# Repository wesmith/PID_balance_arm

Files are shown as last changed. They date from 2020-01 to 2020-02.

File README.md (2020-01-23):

PID_balance_arm

Implement and experiment with a balancing arm that demonstrates PID control, based upon
the project by Electronoobs:

https://www.youtube.com/watch?v=JFTJ2SS4xyA

I want to thank Electronoobs for pushing me over the edge to finally get a 3D printer
after watching this video.

For the 3D modeling, .blend and .stl files were created with Blender,
.gcode files were created with Cura, and printed on an Ender 3 Pro.

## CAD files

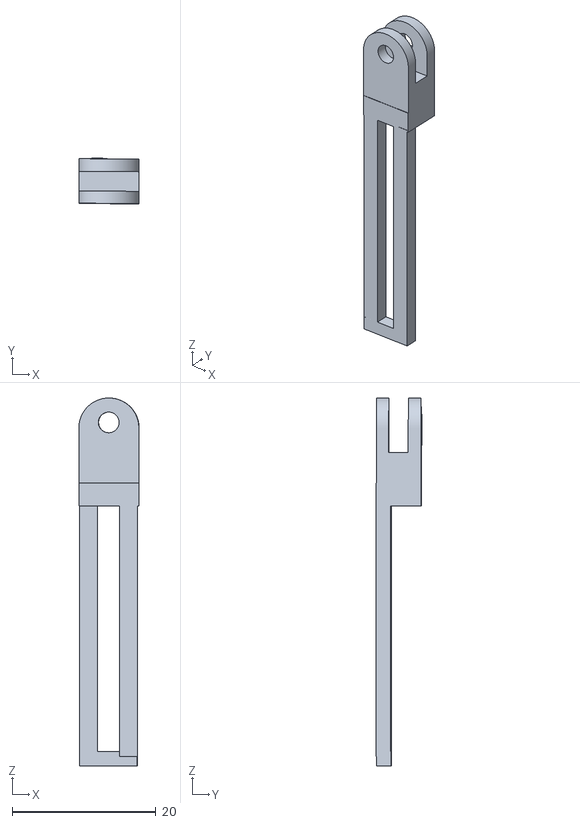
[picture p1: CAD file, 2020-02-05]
electronoobs_balance_3D_files/stl/ws-modified-top-bottom-hinge-single.stl
8.41 x 6.46 x 51.2

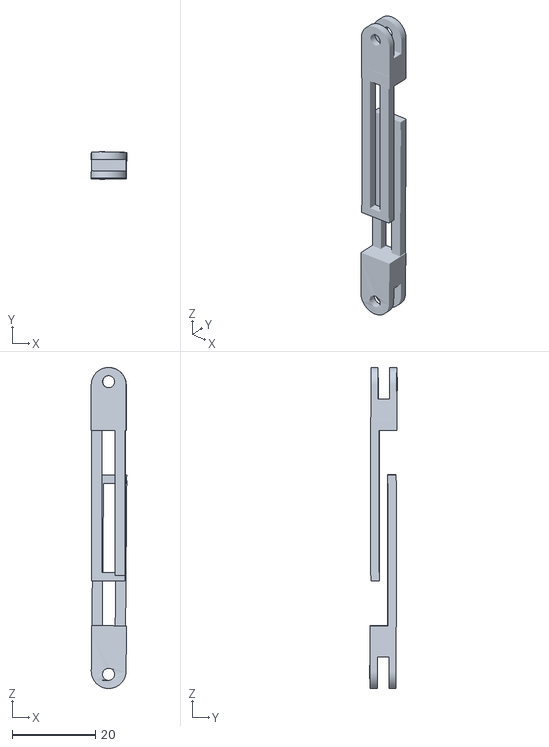
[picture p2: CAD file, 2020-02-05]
electronoobs_balance_3D_files/stl/ws-modified-top-bottom-hinge.stl
8.53 x 6.70 x 77.0

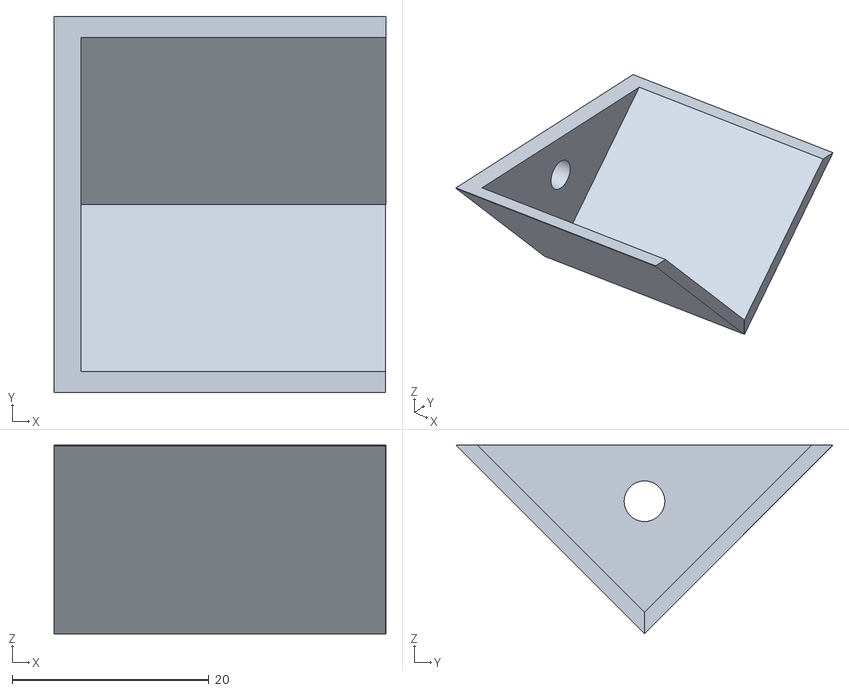
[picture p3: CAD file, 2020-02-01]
electronoobs_balance_3D_files/stl/ws-end_stop.stl
33.7 x 38.2 x 19.2

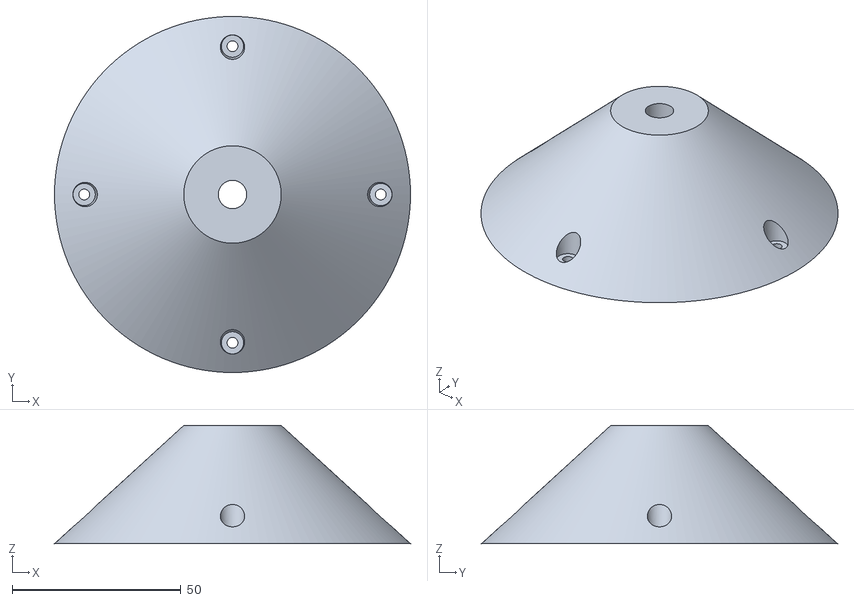
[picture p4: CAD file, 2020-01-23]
electronoobs_balance_3D_files/stl/Base.stl
105.6 x 105.6 x 35.1

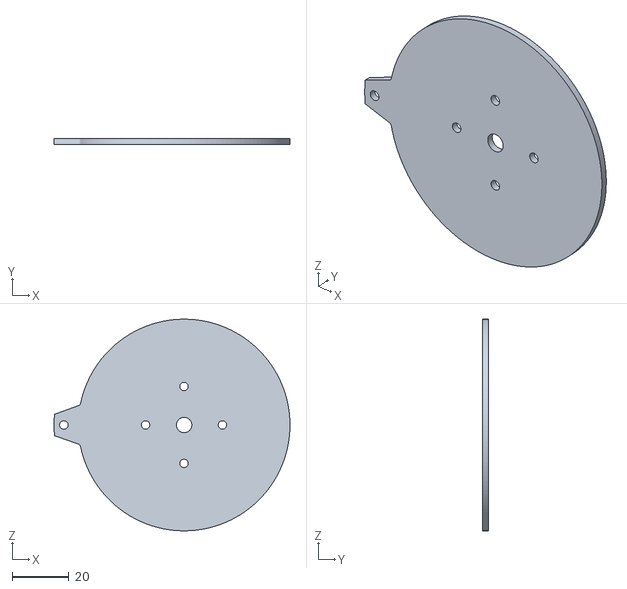
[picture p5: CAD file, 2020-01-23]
electronoobs_balance_3D_files/stl/Disc3.stl
82.9 x 2.00 x 74.4

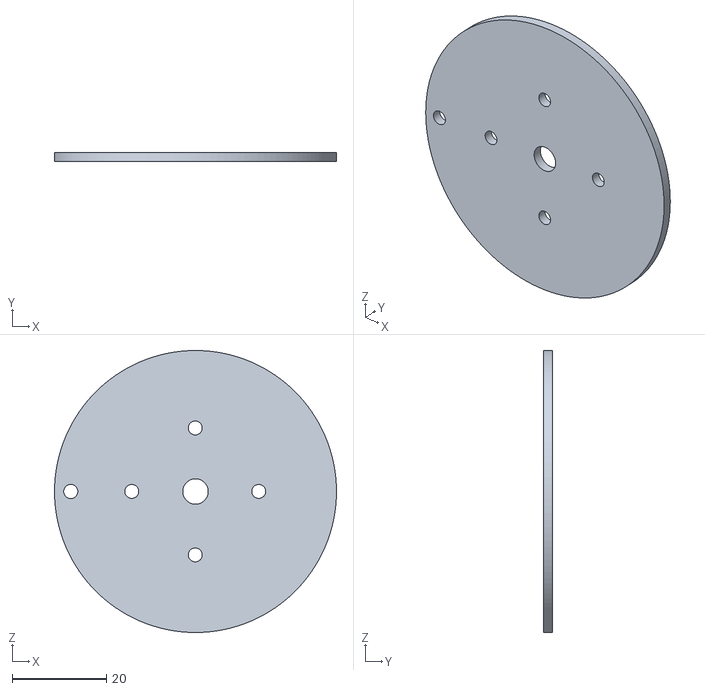
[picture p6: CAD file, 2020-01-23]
electronoobs_balance_3D_files/stl/Disc.stl
60.0 x 2.00 x 60.0

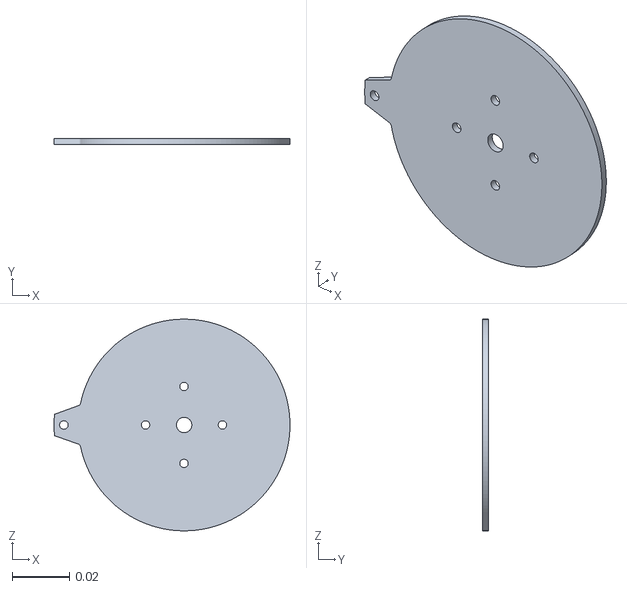
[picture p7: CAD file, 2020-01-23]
electronoobs_balance_3D_files/stl/WS-disc3-scaled-shifted.stl
0.0828 x 0.002 x 0.0743

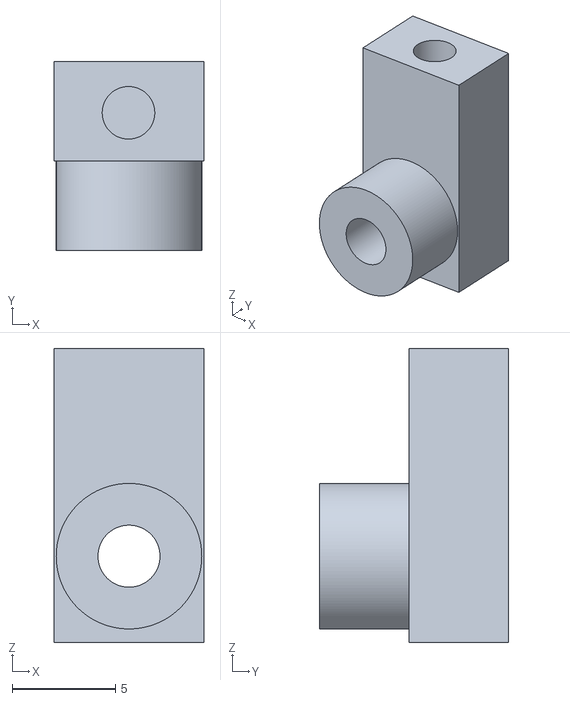
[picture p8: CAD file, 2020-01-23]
electronoobs_balance_3D_files/stl/Small_hinge_3.stl
7.23 x 9.14 x 14.2

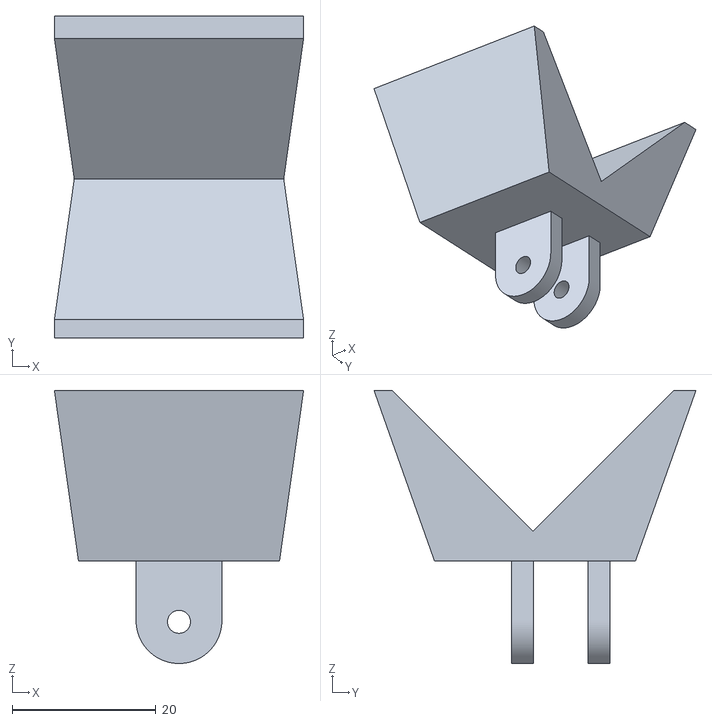
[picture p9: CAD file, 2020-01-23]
electronoobs_balance_3D_files/stl/Hinge_2.stl
34.7 x 44.8 x 38.0

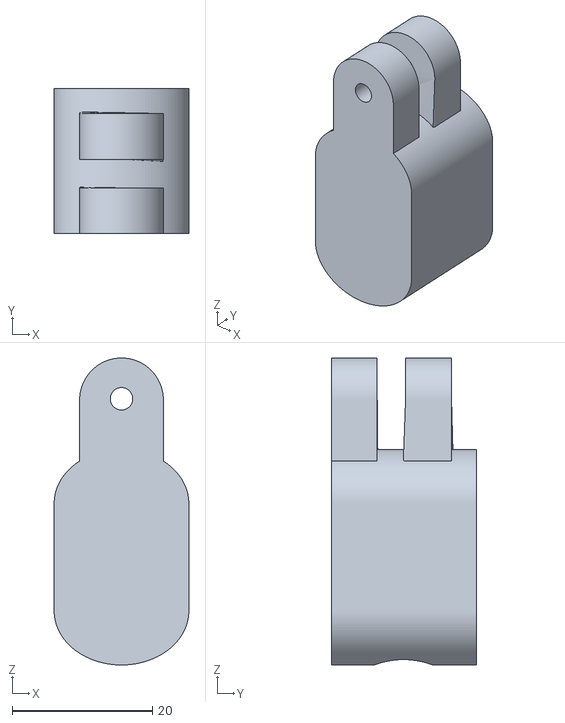
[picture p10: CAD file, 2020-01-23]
electronoobs_balance_3D_files/stl/Hinge_1.stl
19.2 x 20.8 x 43.9

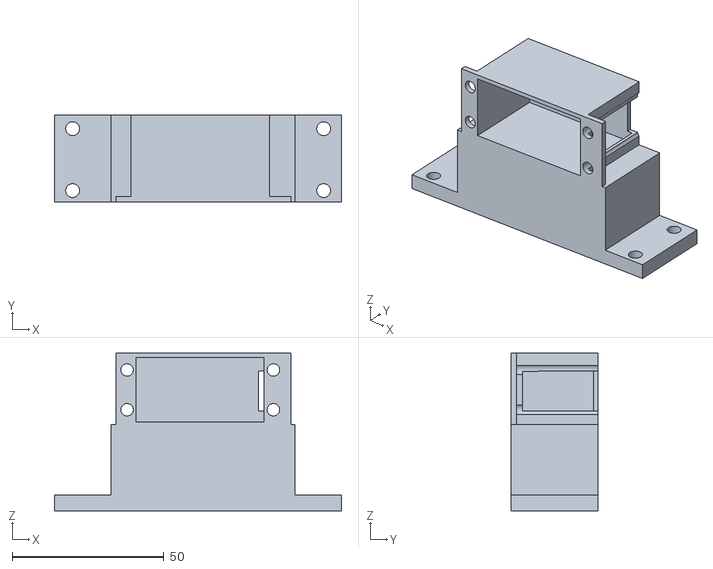
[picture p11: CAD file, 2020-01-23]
electronoobs_balance_3D_files/stl/Servo_support.stl
94.6 x 28.7 x 51.9

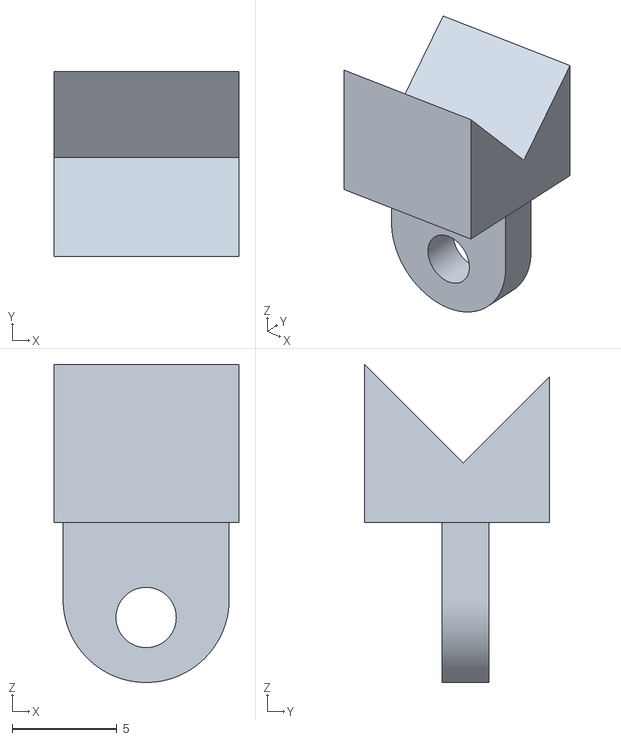
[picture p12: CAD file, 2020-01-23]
electronoobs_balance_3D_files/stl/Small_hinge_1.stl
8.83 x 8.83 x 15.2

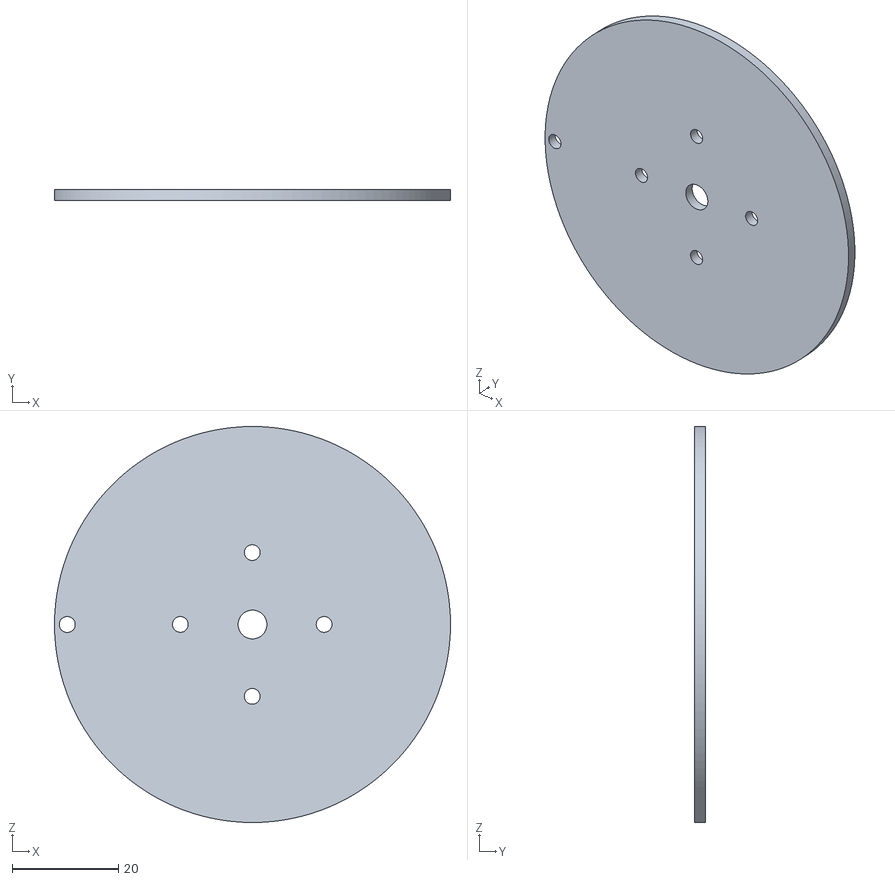
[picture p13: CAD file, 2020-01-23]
electronoobs_balance_3D_files/stl/Disc2.stl
74.4 x 2.00 x 74.4

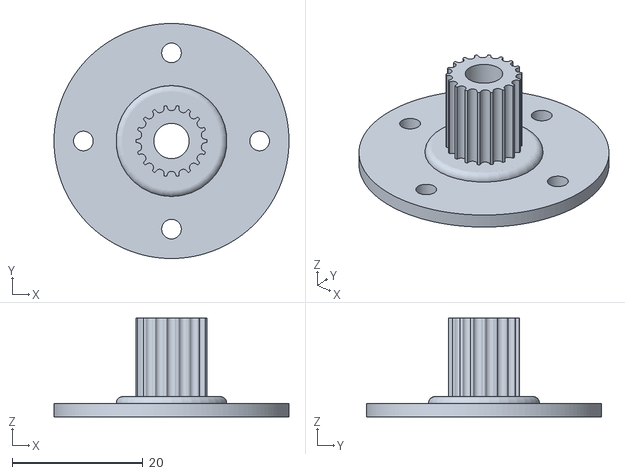
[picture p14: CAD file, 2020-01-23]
electronoobs_balance_3D_files/stl/6. Small_gear (2x).stl
36.0 x 36.0 x 15.1

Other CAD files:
electronoobs_balance_3D_files/stl/ws-bar.stl
electronoobs_balance_3D_files/stl/Small_hinge_2.stl
electronoobs_balance_3D_files/stl/ws-lever.stl
electronoobs_balance_3D_files/stl/End_stop.stl
electronoobs_balance_3D_files/blend/Balanza PID pingpong.blend
electronoobs_balance_3D_files/blend/ws-bar.blend
electronoobs_balance_3D_files/blend/ws-lever.blend
electronoobs_balance_3D_files/blend/ws-modified-top-bottom-hinge.blend

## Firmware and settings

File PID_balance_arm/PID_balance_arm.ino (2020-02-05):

/*PID_balance_arm.ino
 * 
 * WESmith 02/05/20
 * 
 * balance a ping-pong ball along a balance arm using PID feedback 
 * 
 * original code by http://electronoobs.com/eng_arduino_tut100_code1.php , 
 * modified for experimentation
 * 
 * hardware: Arduino UNO, GP2Y0A21YK0F_5V IR distance sensor (connected to pin A0), 
 *           and the Tower Pro SG-5010 servo (connected to pin 9)
 * 
 * NOTE: Before loading this program into the Arduino, remove the lever arm from the servo
 *       to prevent spurious out-of-bound motion of the servo during program startup 
 *       from damaging/stressing the setup. After the program has initialized, put the lever 
 *       arm on the servo in the horizontal position, which corresponds to the beginning 
 *       servo_ang of 90 deg. 
 */

#include "IR_sensor.h" 
#include <Servo.h>

int NMEAS             =  100; // 60  number of distance measurements to average for 1 point
const int MINANG      =  65; // in deg
const int MAXANG      = 115; 

const byte sensor_pin =  A0;
const byte servo_pin  =   9;


float servo_ang = 90; 
int   baseline  = 90; // baseline angle of slide

unsigned int analog; // not used in this sketch, but required for get_dist()
unsigned int distance;

DistSensor sensor(DistSensor::GP2Y0A21YK0F_5V, sensor_pin);
Servo servo;

////////////////////////Variables///////////////////////
float tt;
float prev_error = 0;
float error      = 0;
int   period     = 20;  // refresh rate of the loop in ms
///////////////////////////////////////////////////////

///////////////////PID constants///////////////////////
float alpha = 0.9; 
float kp = 2.0; //
float ki = 20.0; //
float kd = 600.0; //
float setpoint = 275;  // desired placement of the ball in mm
float PID_p, PID_i, PID_d, PID_total;
int   PID_i_bound = 10;
///////////////////////////////////////////////////////


void waitForSerial() {
  while(Serial.available()){Serial.read();}
  while (!Serial.available()) { }
  //Serial.println(Serial.read());
  //Serial.println("");
}

void setup() {
  Serial.begin(9600);
  servo.attach(servo_pin);
  delay(100);
  servo.write(baseline);
  pinMode(sensor_pin, INPUT);
  //sensor.print_LUT();  // diagnostic

  //Serial.println("");
  //Serial.println("In setup(): CR to continue");
  //waitForSerial();
  Serial.println("loop has begun");

  tt = millis();
}

void loop() {
  
  if (millis() > tt + period) {
    
    tt = millis();    
    sensor.get_dist(analog, distance, NMEAS);  // analog not used here
    error = setpoint - distance;
    
    PID_p = kp * error;
    
    float diff = error - prev_error;     
    PID_d = kd * (diff/(float)period);
      
    if((error > -PID_i_bound) && (error < PID_i_bound))
    {
      PID_i = PID_i + (ki * error);
    }
    else
    {
      PID_i = 0;
    }
  
    PID_total = PID_p + PID_i + PID_d;  
    servo_ang = alpha * servo_ang + (1.0 - alpha) * PID_total; 
    //servo_ang = baseline + PID_total; ;
  
    if(servo_ang < MINANG) {servo_ang = MINANG;}
    if(servo_ang > MAXANG) {servo_ang = MAXANG;} 

    /*
    Serial.print("error: ");
    Serial.print(error);
    Serial.print("  servo_ang: ");
    Serial.println(servo_ang);
    */

    servo.write((int)servo_ang);  
    prev_error = error;
  }
}

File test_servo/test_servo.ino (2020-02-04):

/*
sketch_8_4 from 'Arduino Cookbook'

WSmith 01/23/20, run servo from serial port, set empirical limits

Running the Tower Pro SG-5010 servo
*/

#include <Servo.h>

Servo myservo;

int MINANG = 0; 
int MAXANG = 172; // by experiment: anything higher causes chatter
int INIT   = 90;  // 90 degrees
int angle; 
int val = 0;
char txt[100];

void setup()
{
 Serial.begin(9600);
 myservo.attach(9); 
 delay(100);
 myservo.write(INIT);
 delay(100);
 
 /*
 - spec sheet shows 600 us to 2400 us pulse widths
 - default values (which are?) gives range about 95-98% of desired range
 - you don't get the full 180 deg range, max looks like up to 170 deg or so
 - 600, 2400 gives range that looks like default range
 - 1000, 2000 gives 50% of desired range
 */
}

void loop()
{
  if ( Serial.available() )
  {
    char ch = Serial.read();
    
    if ( ch >= '0' && ch <= '9' ) // is ch a number?
      val = val * 10 + ch - '0'; 
      
    else if (ch == 10) // end of line
    {
      angle = val;
      if (angle > MAXANG) {angle = MAXANG;}
      if (angle < MINANG) {angle = MINANG;}
      myservo.write( angle );
      sprintf(txt, "Desired angle %i, Thresholded input %i", val, angle);
      Serial.println( txt );
      val = 0;
    }
  } 
}

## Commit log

2020-01-23 added 3D files
    [6. Small_gear (2x).stl, Balanza PID pingpong.blend, Base.stl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]
2020-01-23 tested servo, determined limits
2020-01-25 started distance-sensor calibration code
2020-01-27 making calibration measurements, experimenting with delays
2020-01-28 some tweaks to printing, timing
2020-01-29 mods for calibration run
2020-01-29 made a LUT in a c-like manner to guide arduino code
2020-01-30 more calibration tweaking, histograms
2020-01-31 IR distance calibration good enough for PID testing, added electronoobs power-law to compare with linear LUT: linear LUT more accurate
2020-02-01 added model for sensor mount on slide
    [ws-end_stop.stl]
2020-02-01 calibration for GP2Y0A21YKOF sensor in new mount on slide: getting there, 2mm - 3mm accuracy over 100mm to 350mm range
2020-02-03 got it working, updated calibration, working well between 100mm and 350mm, getting 2mm to 4mm stddev
2020-02-04 finished refactoring, tweaked calibration, ready to merge
2020-02-05 new parts to print
    [ws-modified-top-bottom-hinge-single.stl, ws-modified-top-bottom-hinge.blend, ws-modified-top-bottom-hinge.stl]
2020-02-05 first cut at PID experiments
